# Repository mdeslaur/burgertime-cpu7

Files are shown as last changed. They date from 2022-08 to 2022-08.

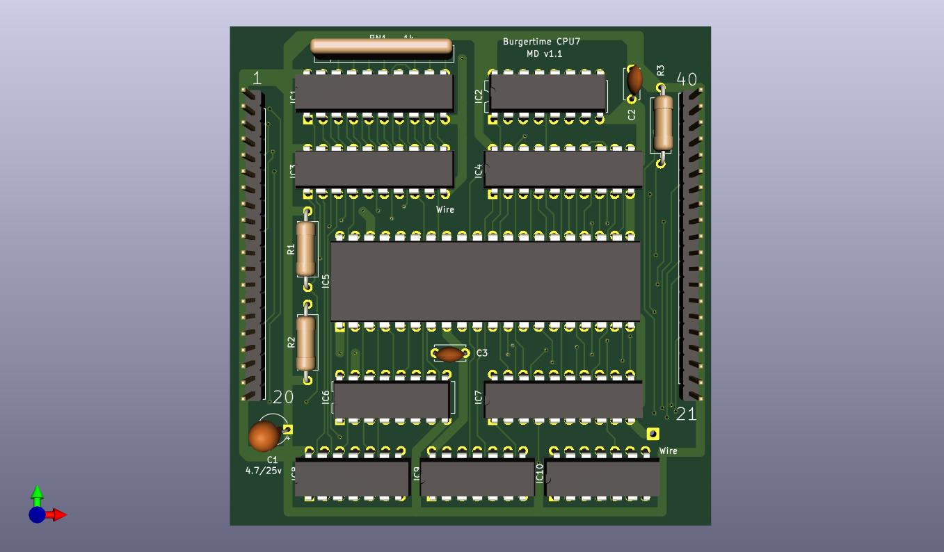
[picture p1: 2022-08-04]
docs/burgertime-cpu7.jpg

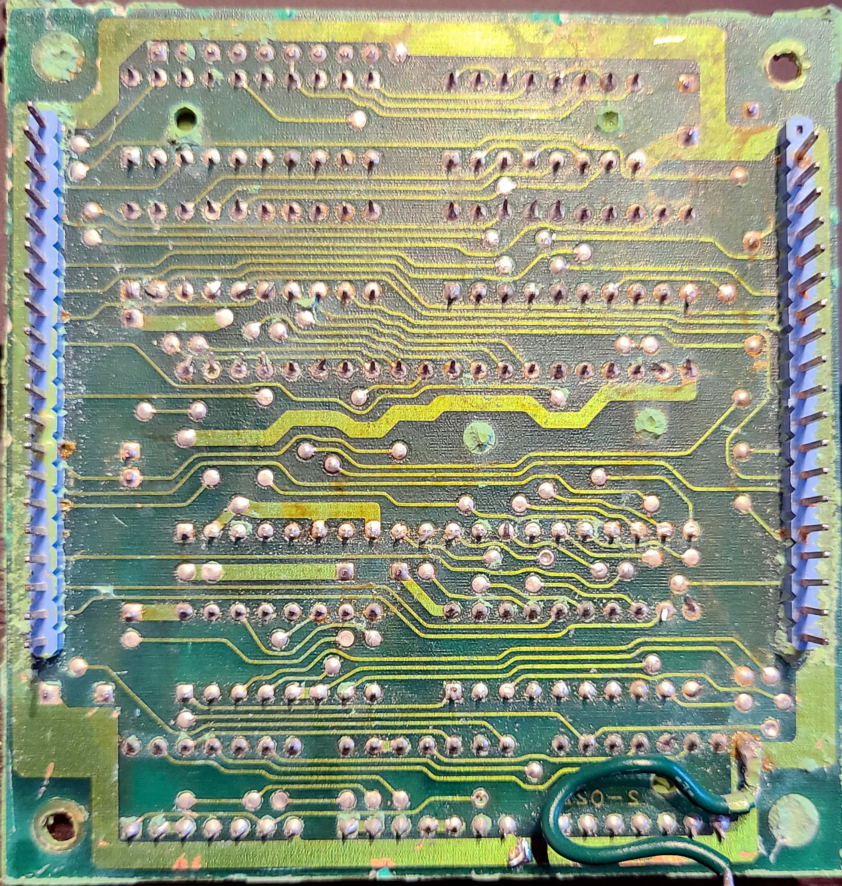
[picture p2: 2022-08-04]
docs/pcb-back-flipped.jpg

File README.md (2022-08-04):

# Burgertime CPU-7 module

This is a 1-for-1 reproduction of the Burgertime CPU-7 module which came
encapsulated in epoxy.

The layout and routing is as close to original as possible.

The original board has a wire running from pin 10 of IC3 to a pad on the
lower right corner, and then to the ground plane of the main PCB stack. This
reproduction may work without it, but it is best to add it like on the
original.

Pictures of the original board and a PDF schematic are available in the
docs directory. The gerbers for JLCPCB are in the zip file in the gerbers
directory.

Change history:  
1.0 - Initial version  
1.1 - Updated to add component values, gerbers, and docs.  

To Do:  

Marc Deslauriers  
2022-08-04

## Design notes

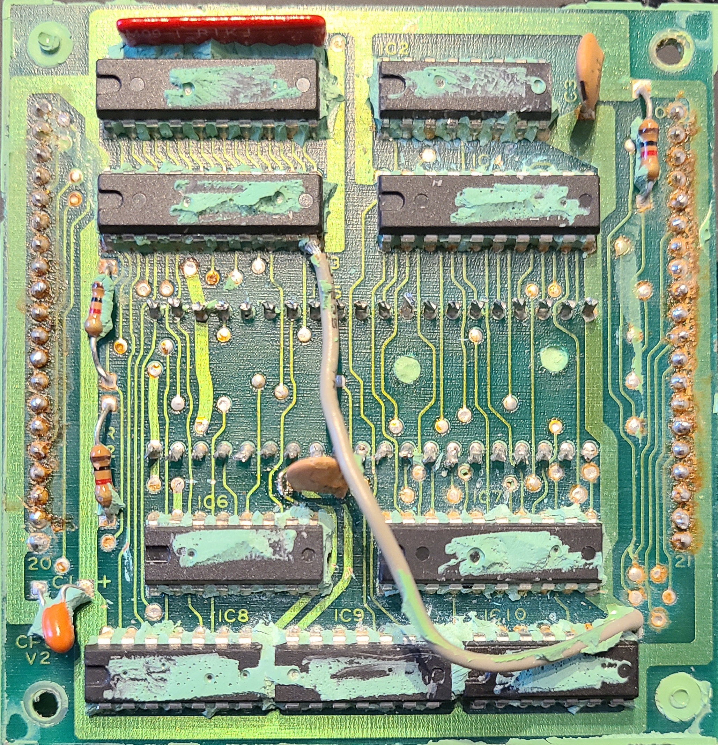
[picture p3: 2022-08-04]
docs/pcb-front.jpg

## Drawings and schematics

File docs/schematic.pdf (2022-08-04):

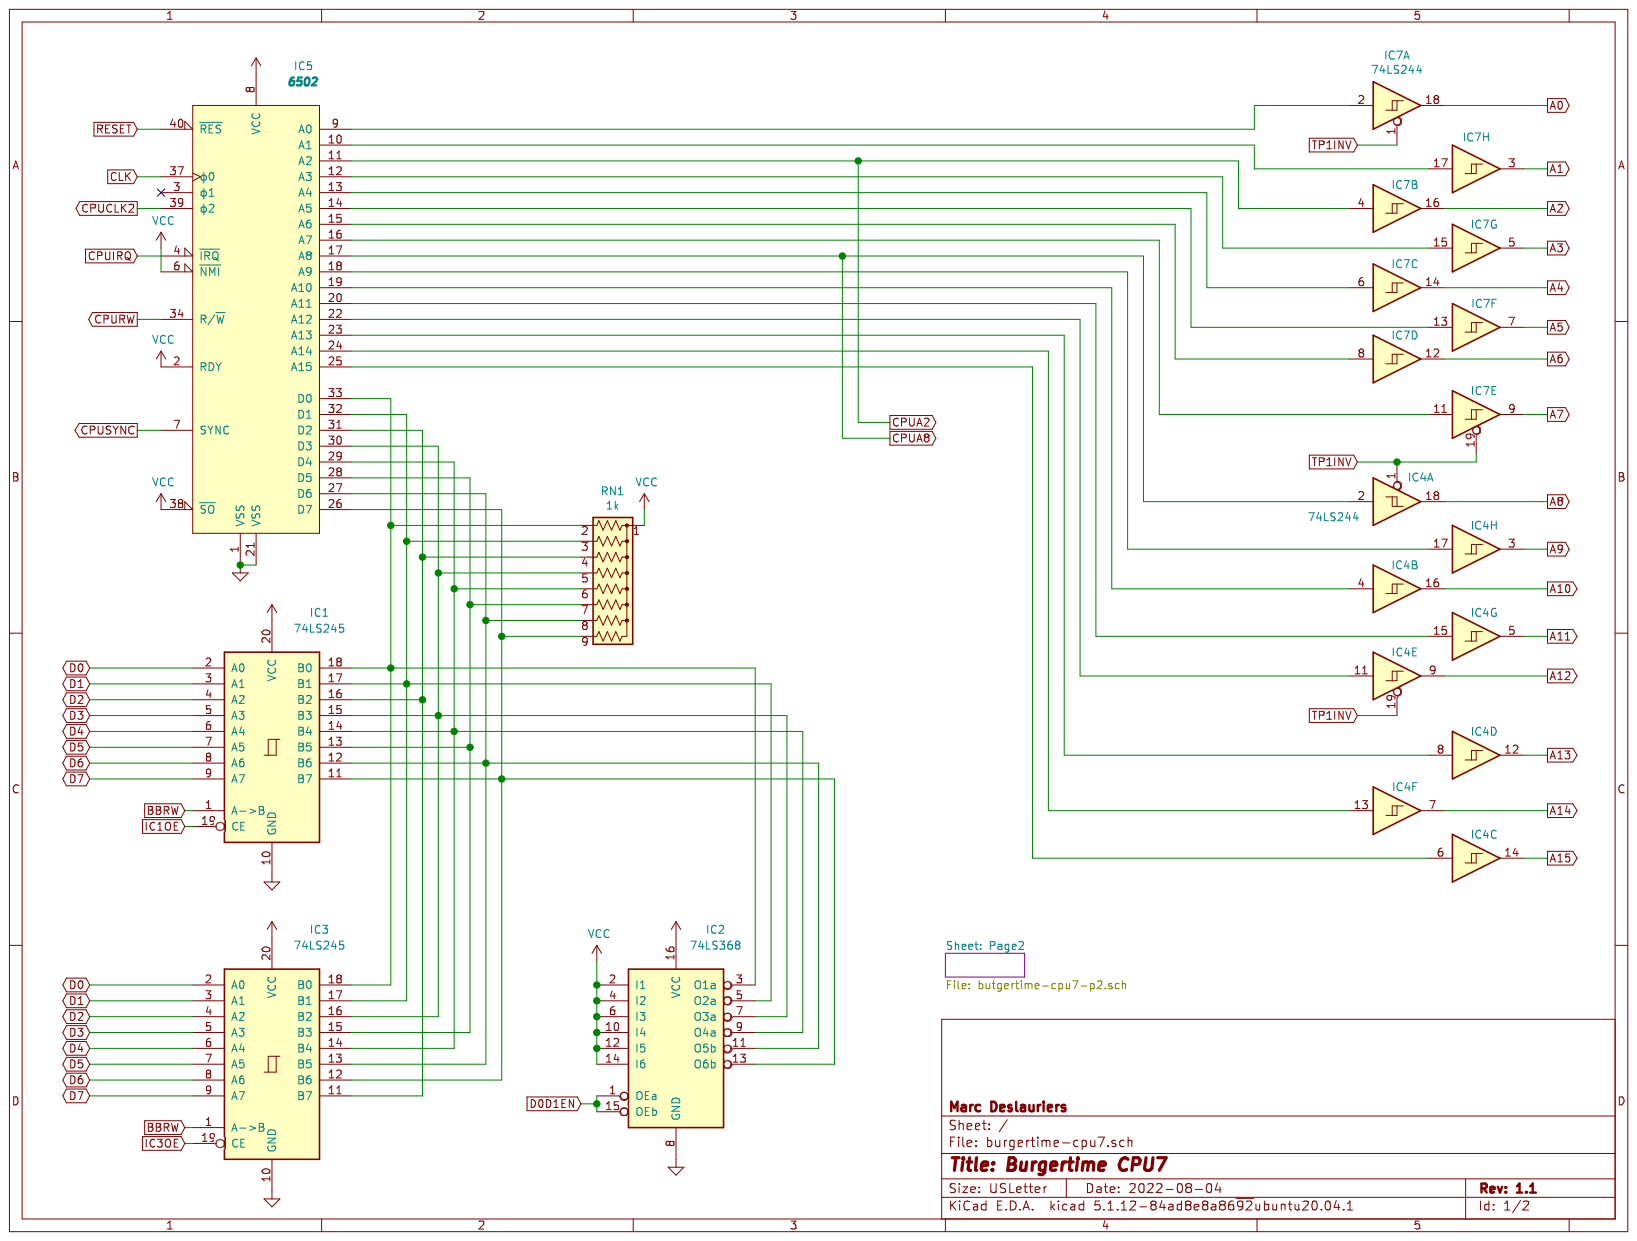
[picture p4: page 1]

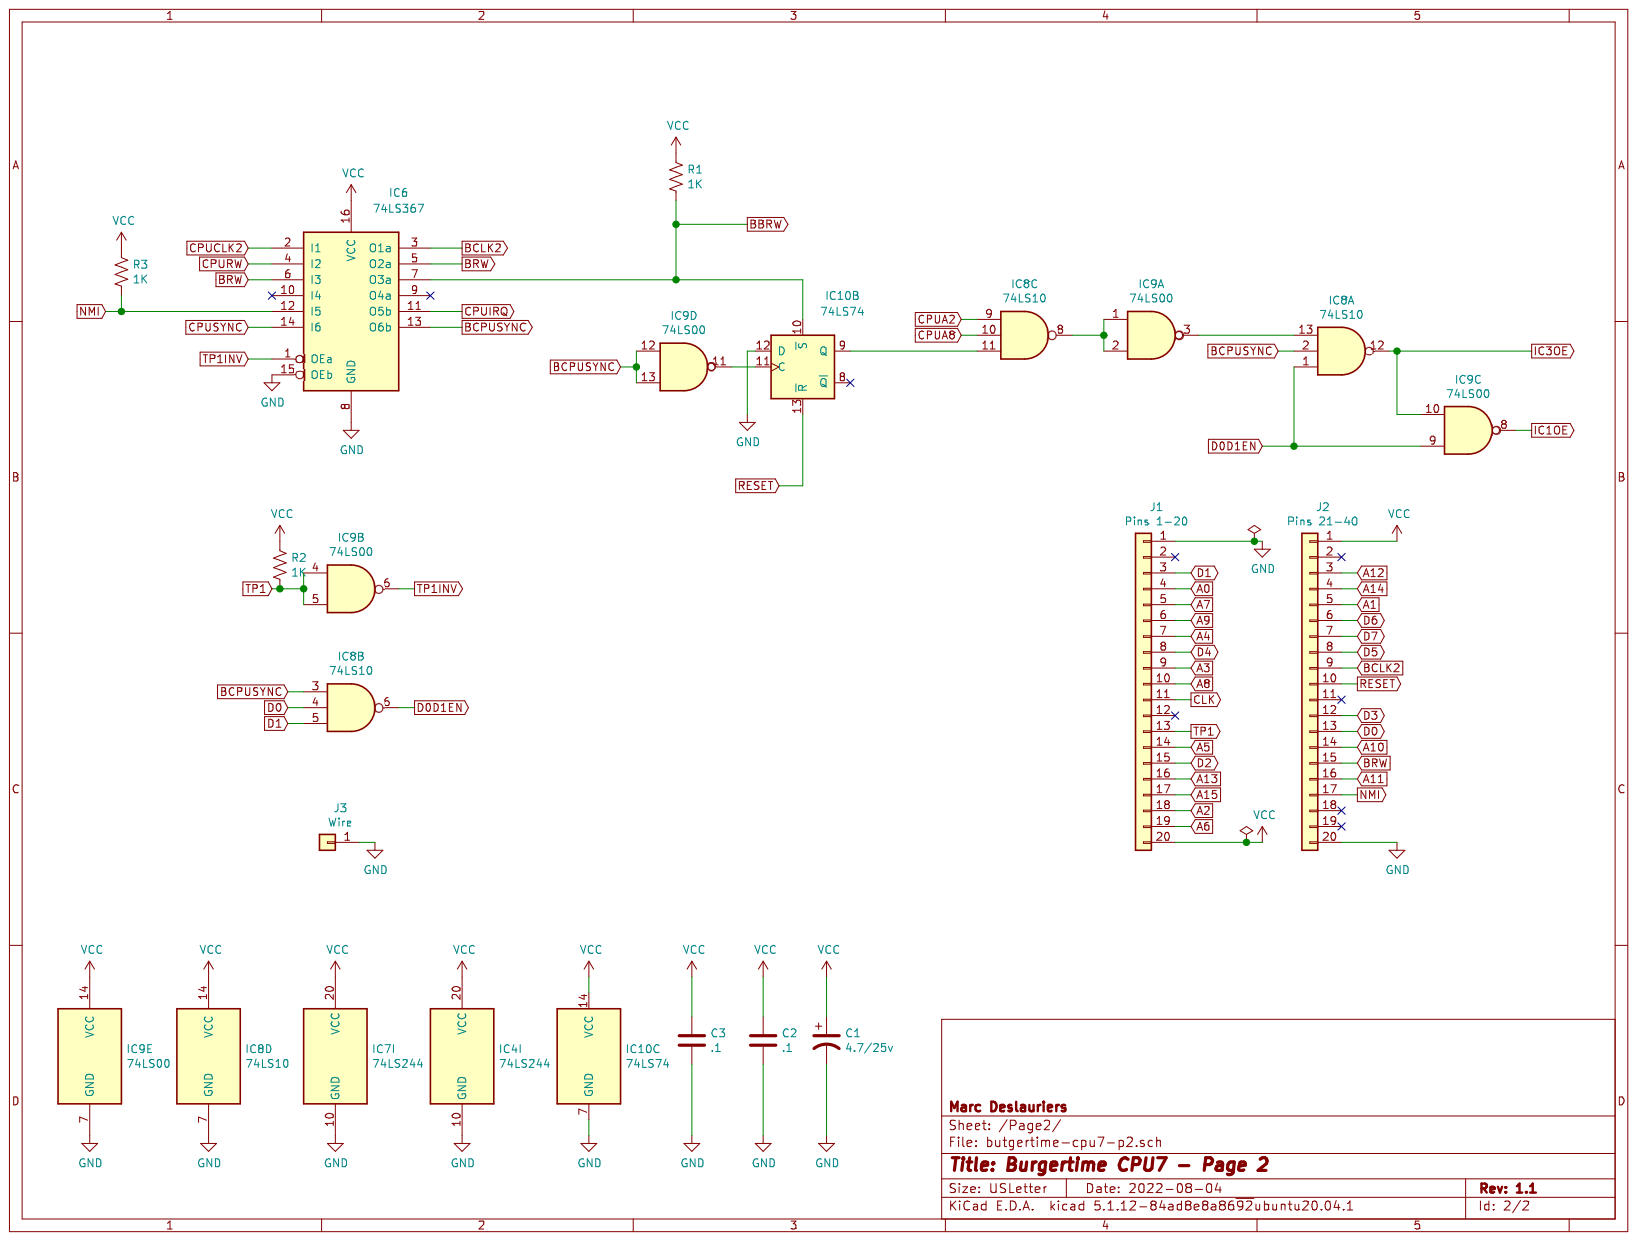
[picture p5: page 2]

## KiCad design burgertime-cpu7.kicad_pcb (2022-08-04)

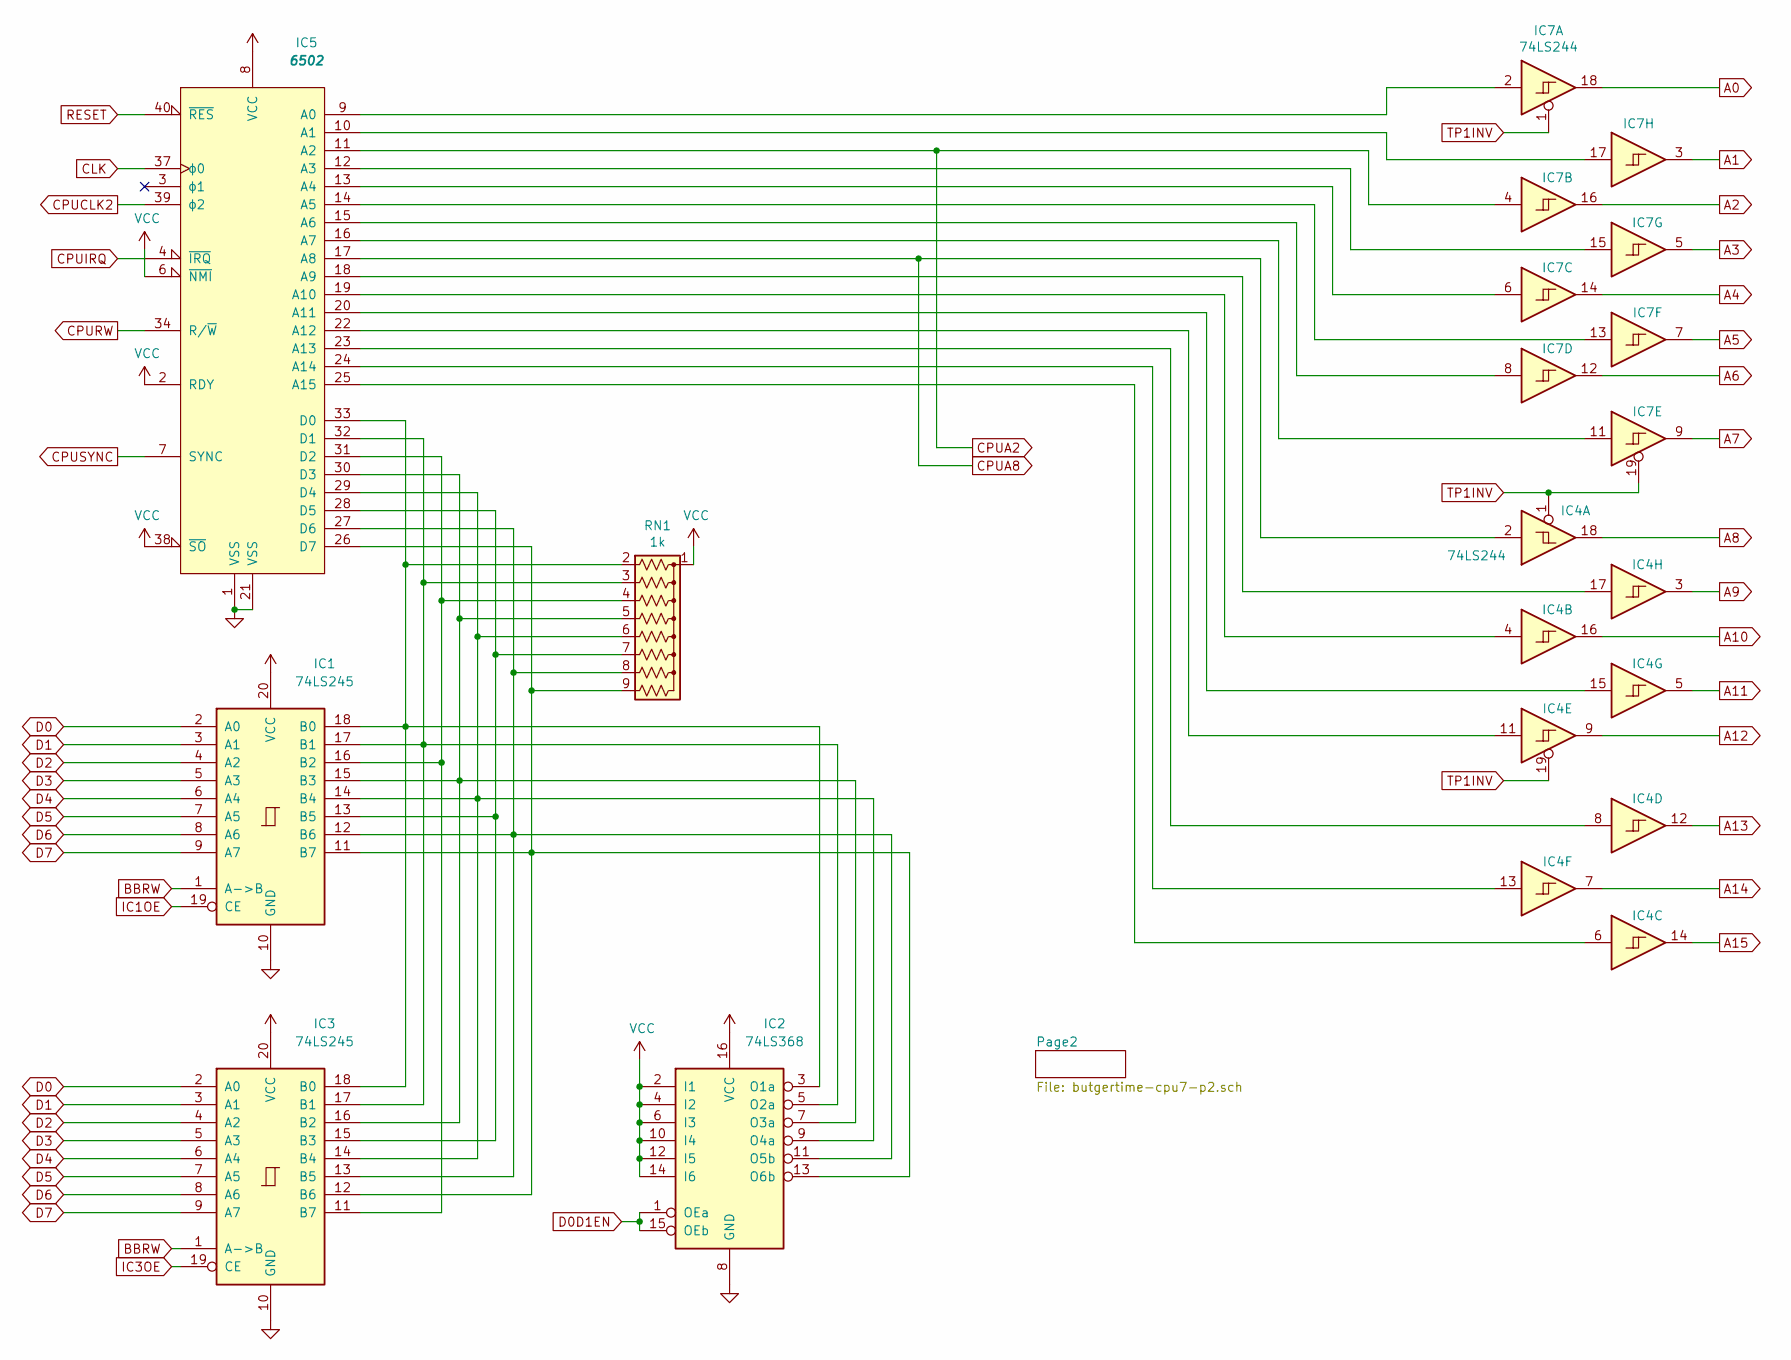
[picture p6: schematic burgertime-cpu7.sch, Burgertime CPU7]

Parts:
IC1, IC3: 74LS245; DIP-20_W7.62mm
IC2: 74LS368; DIP-16_W7.62mm
IC4, IC7: 74LS244; DIP-20_W7.62mm
IC5: 6502; DIP-40_W15.24mm
RN1: 1k; R_Array_SIP9

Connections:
A0: IC7.18; also elsewhere on the board
A1: IC7.3; also elsewhere on the board
A2: IC7.16; also elsewhere on the board
A3: IC7.5; also elsewhere on the board
A4: IC7.14; also elsewhere on the board
A5: IC7.7; also elsewhere on the board
A6: IC7.12; also elsewhere on the board
A7: IC7.9; also elsewhere on the board
A8: IC4.18; also elsewhere on the board
A9: IC4.3; also elsewhere on the board
A10: IC4.16; also elsewhere on the board
A11: IC4.5; also elsewhere on the board
A12: IC4.9; also elsewhere on the board
A13: IC4.12; also elsewhere on the board
A14: IC4.7; also elsewhere on the board
A15: IC4.14; also elsewhere on the board
BBRW: IC1.1 (A->B), IC3.1 (A->B); also elsewhere on the board
CLK: IC5.37 (ϕ0); also elsewhere on the board
CPUA2: IC5.11 (A2), IC7.4; also elsewhere on the board
CPUA8: IC4.2, IC5.17 (A8); also elsewhere on the board
CPUCLK2: IC5.39 (ϕ2); also elsewhere on the board
CPUIRQ: IC5.4 (~IRQ); also elsewhere on the board
CPURW: IC5.34 (R/~W); also elsewhere on the board
CPUSYNC: IC5.7 (SYNC); also elsewhere on the board
D0: IC1.2 (A0), IC3.2 (A0); also elsewhere on the board
D0D1EN: IC2.1 (OEa), IC2.15 (OEb); also elsewhere on the board
D1: IC1.3 (A1), IC3.3 (A1); also elsewhere on the board
D2: IC1.4 (A2), IC3.4 (A2); also elsewhere on the board
D3: IC1.5 (A3), IC3.5 (A3); also elsewhere on the board
D4: IC1.6 (A4), IC3.6 (A4); also elsewhere on the board
D5: IC1.7 (A5), IC3.7 (A5); also elsewhere on the board
D6: IC1.8 (A6), IC3.8 (A6); also elsewhere on the board
D7: IC1.9 (A7), IC3.9 (A7); also elsewhere on the board
GND: IC1.10 (GND), IC2.8 (GND), IC3.10 (GND), IC5.1 (VSS), IC5.21 (VSS); also elsewhere on the board
IC1OE: IC1.19 (CE); also elsewhere on the board
IC3OE: IC3.19 (CE); also elsewhere on the board
unnamed: IC1.11 (B7), IC2.13 (O6b), IC3.12 (B6), IC5.26 (D7), RN1.9 (R8)
unnamed: IC1.12 (B6), IC2.11 (O5b), IC3.13 (B5), IC5.27 (D6), RN1.8 (R7)
unnamed: IC1.13 (B5), IC3.15 (B3), IC5.28 (D5), RN1.7 (R6)
unnamed: IC1.14 (B4), IC2.9 (O4a), IC3.14 (B4), IC5.29 (D4), RN1.6 (R5)
unnamed: IC1.15 (B3), IC2.7 (O3a), IC3.16 (B2), IC5.30 (D3), RN1.5 (R4)
unnamed: IC1.16 (B2), IC3.11 (B7), IC5.31 (D2), RN1.4 (R3)
unnamed: IC1.17 (B1), IC2.5 (O2a), IC3.17 (B1), IC5.32 (D1), RN1.3 (R2)
unnamed: IC1.18 (B0), IC2.3 (O1a), IC3.18 (B0), IC5.33 (D0), RN1.2 (R1)
unnamed: IC4.4, IC5.19 (A10)
unnamed: IC4.6, IC5.25 (A15)
unnamed: IC4.8, IC5.23 (A13)
unnamed: IC4.11, IC5.22 (A12)
unnamed: IC4.13, IC5.24 (A14)
unnamed: IC4.15, IC5.20 (A11)
unnamed: IC4.17, IC5.18 (A9)
unnamed: IC5.9 (A0), IC7.2
unnamed: IC5.10 (A1), IC7.17
unnamed: IC5.12 (A3), IC7.15
unnamed: IC5.13 (A4), IC7.6
unnamed: IC5.14 (A5), IC7.13
unnamed: IC5.15 (A6), IC7.8
unnamed: IC5.16 (A7), IC7.11
RESET: IC5.40 (~RES); also elsewhere on the board
TP1INV: IC4.1, IC4.19, IC7.1, IC7.19; also elsewhere on the board
VCC: IC1.20 (VCC), IC2.2 (I1), IC2.4 (I2), IC2.6 (I3), IC2.10 (I4), IC2.12 (I5), IC2.14 (I6), IC2.16 (VCC), IC3.20 (VCC), IC5.2 (RDY), IC5.6 (~NMI), IC5.8 (VCC), IC5.38 (~SO), RN1.1 (common); also elsewhere on the board

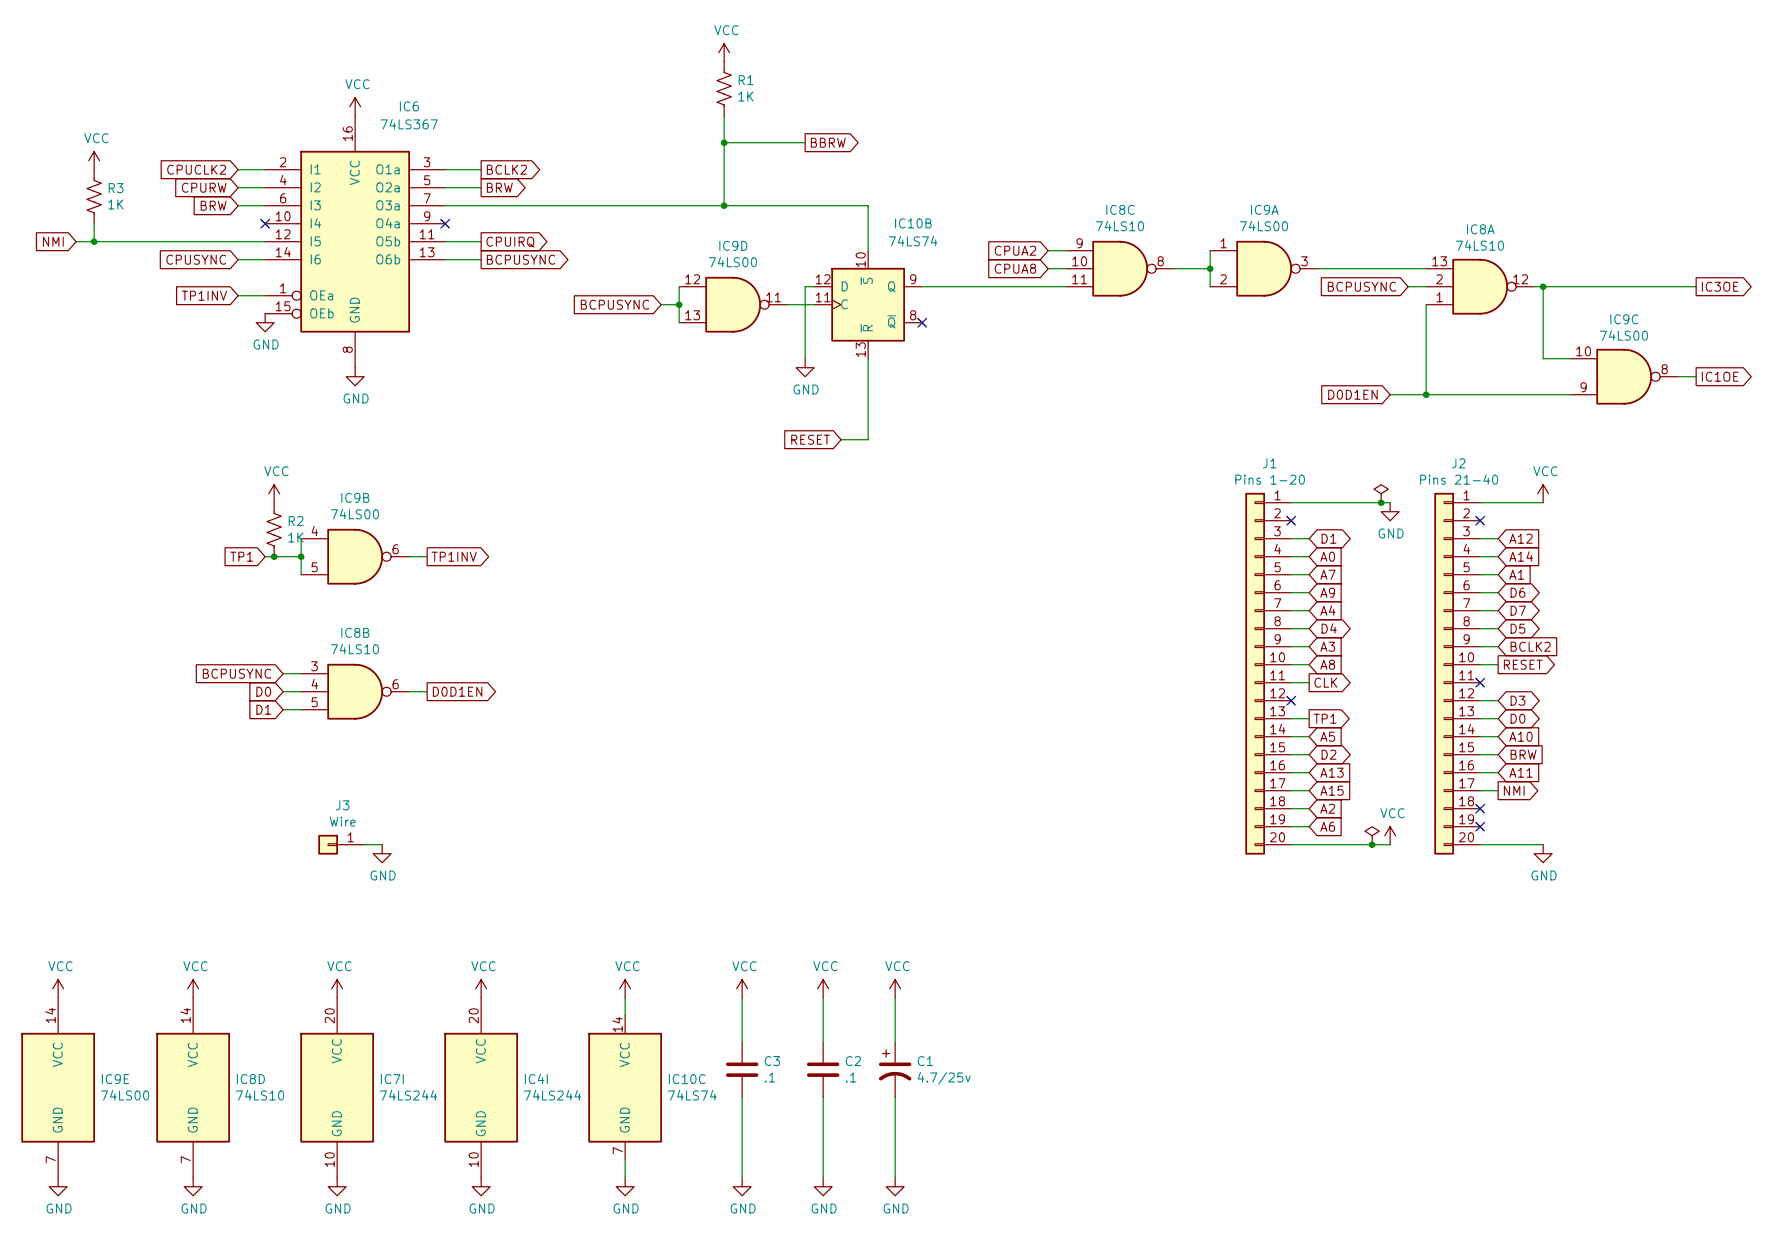
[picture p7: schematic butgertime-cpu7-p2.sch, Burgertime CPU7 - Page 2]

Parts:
C1: 4.7/25v; CP_Radial_Tantal_D5.0mm_P5.00mm
C2, C3: .1; C_Disc_D5.0mm_W2.5mm_P5.00mm
IC4, IC7: 74LS244; DIP-20_W7.62mm
IC6: 74LS367; DIP-16_W7.62mm
IC8: 74LS10; DIP-14_W7.62mm
IC9: 74LS00; DIP-14_W7.62mm
IC10: 74LS74; DIP-14_W7.62mm
J1: Pins 1-20; PinHeader_1x20_P2.54mm_Vertical
J2: Pins 21-40; PinHeader_1x20_P2.54mm_Vertical
J3: Wire; SolderWire-0.5sqmm_1x01_D0.9mm_OD2.1mm
R1, R2, R3: 1K; R_Axial_DIN0309_L9.0mm_D3.2mm_P12.70mm_Horizontal

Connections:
A0: J1.4; also elsewhere on the board
A1: J2.5; also elsewhere on the board
A2: J1.18; also elsewhere on the board
A3: J1.9; also elsewhere on the board
A4: J1.7; also elsewhere on the board
A5: J1.14; also elsewhere on the board
A6: J1.19; also elsewhere on the board
A7: J1.5; also elsewhere on the board
A8: J1.10; also elsewhere on the board
A9: J1.6; also elsewhere on the board
A10: J2.14; also elsewhere on the board
A11: J2.16; also elsewhere on the board
A12: J2.3; also elsewhere on the board
A13: J1.16; also elsewhere on the board
A14: J2.4; also elsewhere on the board
A15: J1.17; also elsewhere on the board
BBRW: IC6.7 (O3a), IC10.10 (~S), R1.2; also elsewhere on the board
BCLK2: IC6.3 (O1a), J2.9
BCPUSYNC: IC6.13 (O6b), IC8.2, IC8.3, IC9.12, IC9.13
BRW: IC6.5 (O2a), IC6.6 (I3), J2.15
CLK: J1.11; also elsewhere on the board
CPUA2: IC8.9; also elsewhere on the board
CPUA8: IC8.10; also elsewhere on the board
CPUCLK2: IC6.2 (I1); also elsewhere on the board
CPUIRQ: IC6.11 (O5b); also elsewhere on the board
CPURW: IC6.4 (I2); also elsewhere on the board
CPUSYNC: IC6.14 (I6); also elsewhere on the board
D0: IC8.4, J2.13; also elsewhere on the board
D0D1EN: IC8.1, IC8.6, IC9.9; also elsewhere on the board
D1: IC8.5, J1.3; also elsewhere on the board
D2: J1.15; also elsewhere on the board
D3: J2.12; also elsewhere on the board
D4: J1.8; also elsewhere on the board
D5: J2.8; also elsewhere on the board
D6: J2.6; also elsewhere on the board
D7: J2.7; also elsewhere on the board
GND: C1.2, C2.2, C3.2, IC4.10 (GND), IC6.8 (GND), IC6.15 (OEb), IC7.10 (GND), IC8.7 (GND), IC9.7 (GND), IC10.7 (GND), IC10.12 (D), J1.1, J2.20, J3.1; also elsewhere on the board
IC1OE: IC9.8; also elsewhere on the board
IC3OE: IC8.12, IC9.10; also elsewhere on the board
NMI: IC6.12 (I5), J2.17, R3.2
unnamed: IC8.8, IC9.1, IC9.2
unnamed: IC8.13, IC9.3
unnamed: IC8.11, IC10.9 (Q)
unnamed: IC9.11, IC10.11 (C)
RESET: IC10.13 (~R), J2.10; also elsewhere on the board
TP1: IC9.4, IC9.5, J1.13, R2.2
TP1INV: IC6.1 (OEa), IC9.6; also elsewhere on the board
VCC: C1.1, C2.1, C3.1, IC4.20 (VCC), IC6.16 (VCC), IC7.20 (VCC), IC8.14 (VCC), IC9.14 (VCC), IC10.14 (VCC), J1.20, J2.1, R1.1, R2.1, R3.1; also elsewhere on the board

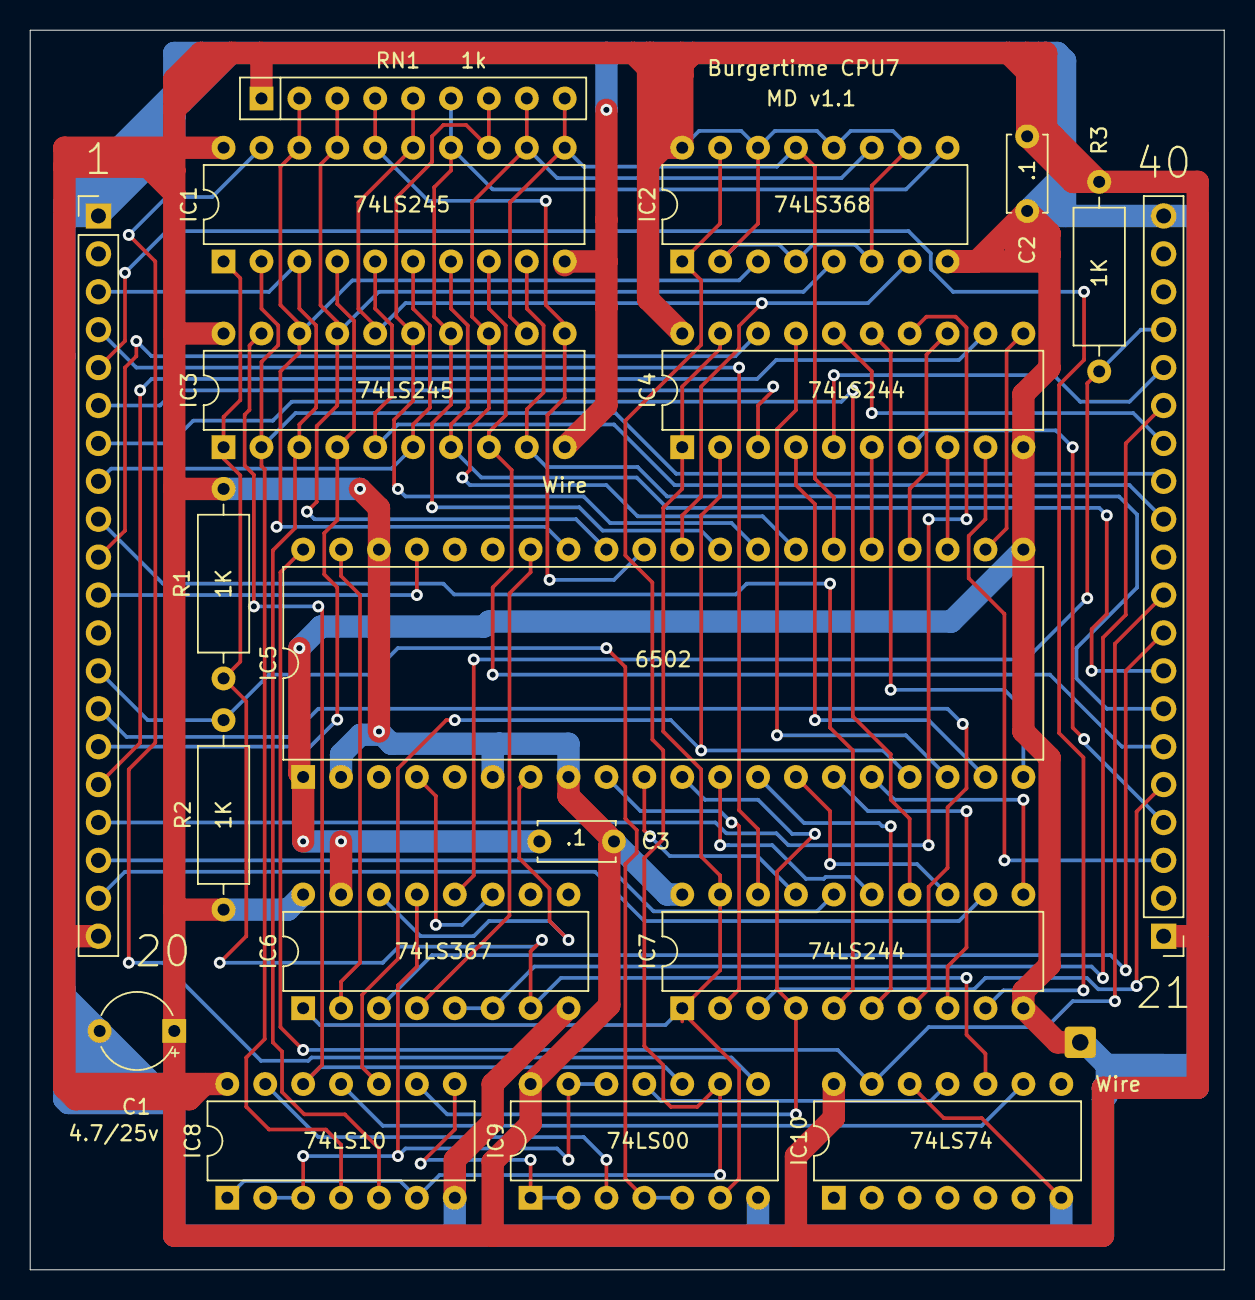
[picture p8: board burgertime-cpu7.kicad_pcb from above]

Board: 2 copper layers, 80.0 x 83.1 mm, 20 parts (0 on the bottom side), 70 nets.
